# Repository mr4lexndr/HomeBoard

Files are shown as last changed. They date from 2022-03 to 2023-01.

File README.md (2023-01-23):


[][cc-by-nc-sa]

[][cc-by-nc-sa]

This work is licensed under a
[Creative Commons Attribution-NonCommercial-ShareAlike 4.0 International License][cc-by-nc-sa].

[cc-by-nc-sa]: http://creativecommons.org/licenses/by-nc-sa/4.0/
[cc-by-nc-sa-image]: https://licensebuttons.net/l/by-nc-sa/4.0/88x31.png
[cc-by-nc-sa-shield]: https://img.shields.io/badge/License-CC%20BY--NC--SA%204.0-lightgrey.svg

# HomeBoard
Simple ESP32 based 4 Channel LV board for controlling Home appliances with [HomeSpan](https://github.com/HomeSpan/HomeSpan).
HomeBoard was created to controll variety of LED strips, and other Low voltage appliances. 

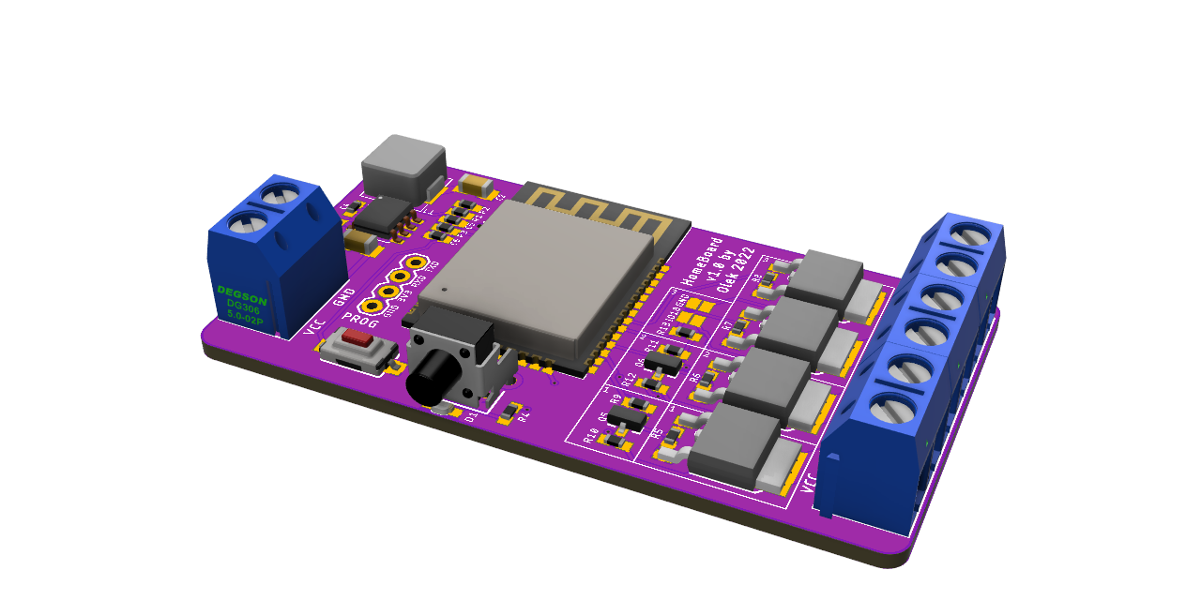
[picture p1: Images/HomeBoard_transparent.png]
HomeBoard


## Main Features
- Supply Voltage 3.5-30V
- Status LED and Control push button for easy configuration
- 4 PWM-eabled channels (0-Vin V, 25A)
- 2 channels can be configured with Logic Level Shifters to drive Neopixels etc.
- Switch or button option vailable.

## User Integration with HomeSpan
Status LED and Control Button are attached to deafault pins for most of the boards. S1 Button is also used as boot button during programming
- LED - GPIO2
- Button - GPIO0

## Variants
Four channels can be configured per requiremnts. Specific sections 1-3 has been marked on PCB. Only one group from each section should be soldered based on selected funtion. Available options:

| Channel | Main Function | Alternative |
| --- | --- | --- |
| 1 | Open Drain | Logic Level (0-Vin) |
| 2 | Open Drain | Logic Level (0-Vin) |
| 3 | Open Drain | Switch (GPIO18) |
| 4 | Open Drain | Switch (GND) |

## TO DO

- 3D printed case
- update power circuit with more common IC
- update programming connector and decrease the size of the board

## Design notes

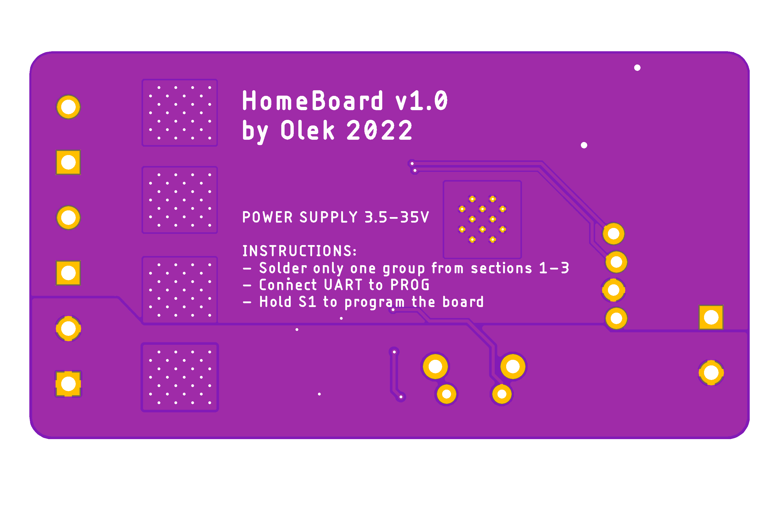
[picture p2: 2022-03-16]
Images/HomeBoard_Bottom.png

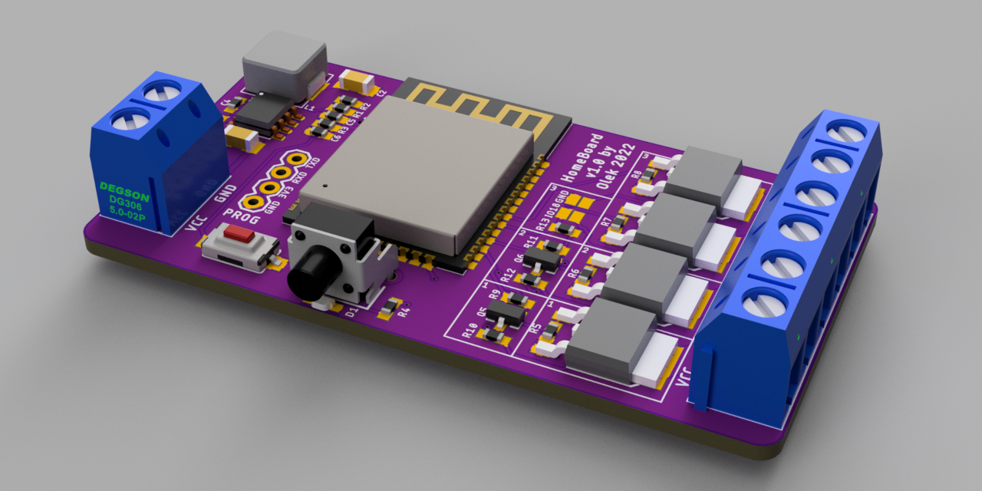
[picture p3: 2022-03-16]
Images/HomeBoard.png

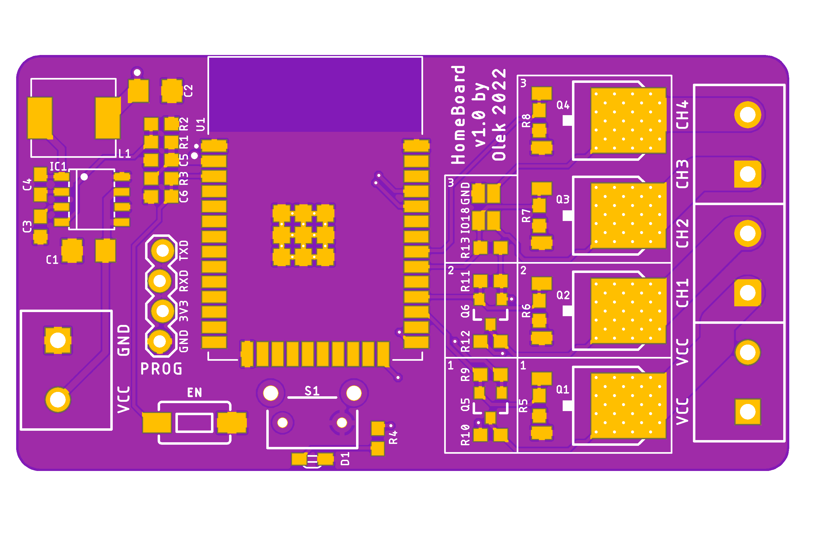
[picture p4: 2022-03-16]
Images/HomeBoard_Top.png

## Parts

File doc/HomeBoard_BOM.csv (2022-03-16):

Qty | Value | Device | Package | Parts | Description
4 |  | CONN_025MM | SCREWTERMINAL-5MM-2 | J1, J2, J3, J4 | Multi connection point. Often used as Generic Header-pin footprint for 0.1 inch spaced/style header connections
1 |  | CONN_04LOCK | 1X04_LOCK | PROG | Multi connection point. Often used as Generic Header-pin footprint for 0.1 inch spaced/style header connections
1 |  | INDUCTOR-7.3X6.6 | INDUCTOR-7.3X6.6 | L1 | Inductor
4 |  | MOSFET-N-DPAK | D-PAK_TO252AA | Q1, Q2, Q3, Q4 | N-Channel MOSFET in various packages
3 | 0.1uF | CAP-0603 | 0603 | C4, C5, C6
10 | 10k | RESISTOR0603 | 0603 | R3, R5, R6, R7, R8, R9, R10, R11, R12, R13 | Generic Resistor Package
1 | 10uF | CAP-1206 | 1206 | C1
1 | 140k | RESISTOR0603 | 0603 | R1 | Generic Resistor Package
1 | 1uF | CAP-0603 | 0603 | C3
1 | 22R | RESISTOR0603 | 0603 | R4 | Generic Resistor Package
1 | 22uF | CAP-1206 | 1206 | C2
1 | 47k | RESISTOR0603 | 0603 | R2 | Generic Resistor Package
2 | BSS138 | MOSFET-N-SOT23-3 | SOT23-3 | Q5, Q6 | N-Channel MOSFET in various packages
1 | ESP32-WROOM-32D | ESP32-WROOM-32D | MODULE_ESP32-WROOM-32D | U1 | Bluetooth, WiFi 802.11b/g/n, Bluetooth v4.2 + EDR, Class 1, 2 and 3 Transceiver Module 2.4GHz ~ 2.5GHz Integrated, Trace Surface Mount Check prices
1 | L6981 | L6981 | SO-8L | IC1 | L6981 38 V, 1.5 A synchronous step-down converter
1 | LTST-S220TBKT | LED-ANGLE-2MM | LED-ANGLE-2MM | D1 | LED (Generic)
1 | MOMENTARY-SWITCH-SPST-PTH-RIGHT-ANGLE-KIT | MOMENTARY-SWITCH-SPST-PTH-RIGHT-ANGLE-KIT | TACTILE_SWITCH_PTH_RIGHT_ANGLE_KIT | S1 | Momentary Switch (Pushbutton) - SPST
1 | MOMENTARY-SWITCH-SPST-SMD-6.0X3.5MM | MOMENTARY-SWITCH-SPST-SMD-6.0X3.5MM | TACTILE_SWITCH_SMD_6.0X3.5MM | EN | Momentary Switch (Pushbutton) - SPST

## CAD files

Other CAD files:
CAD/HomeBoard .f3d
CAD/HomeBoard.f3d

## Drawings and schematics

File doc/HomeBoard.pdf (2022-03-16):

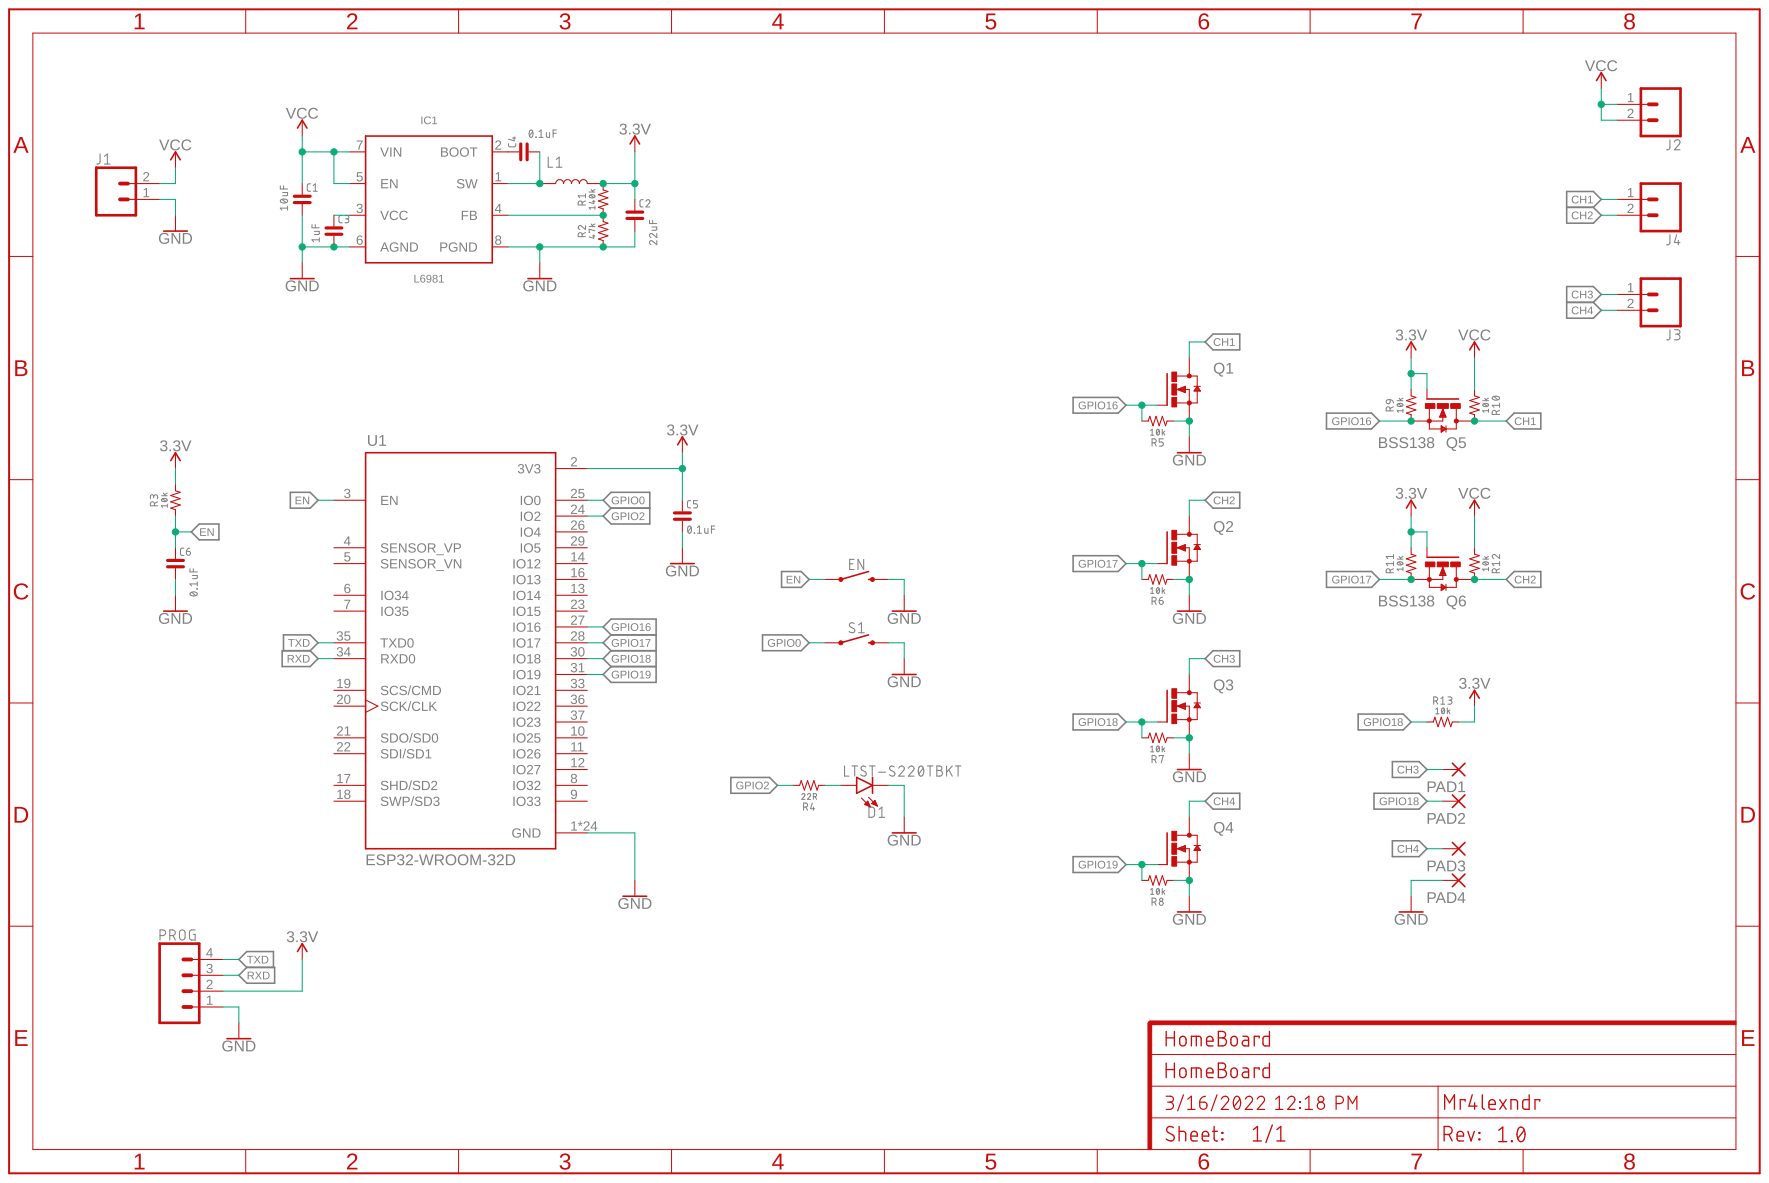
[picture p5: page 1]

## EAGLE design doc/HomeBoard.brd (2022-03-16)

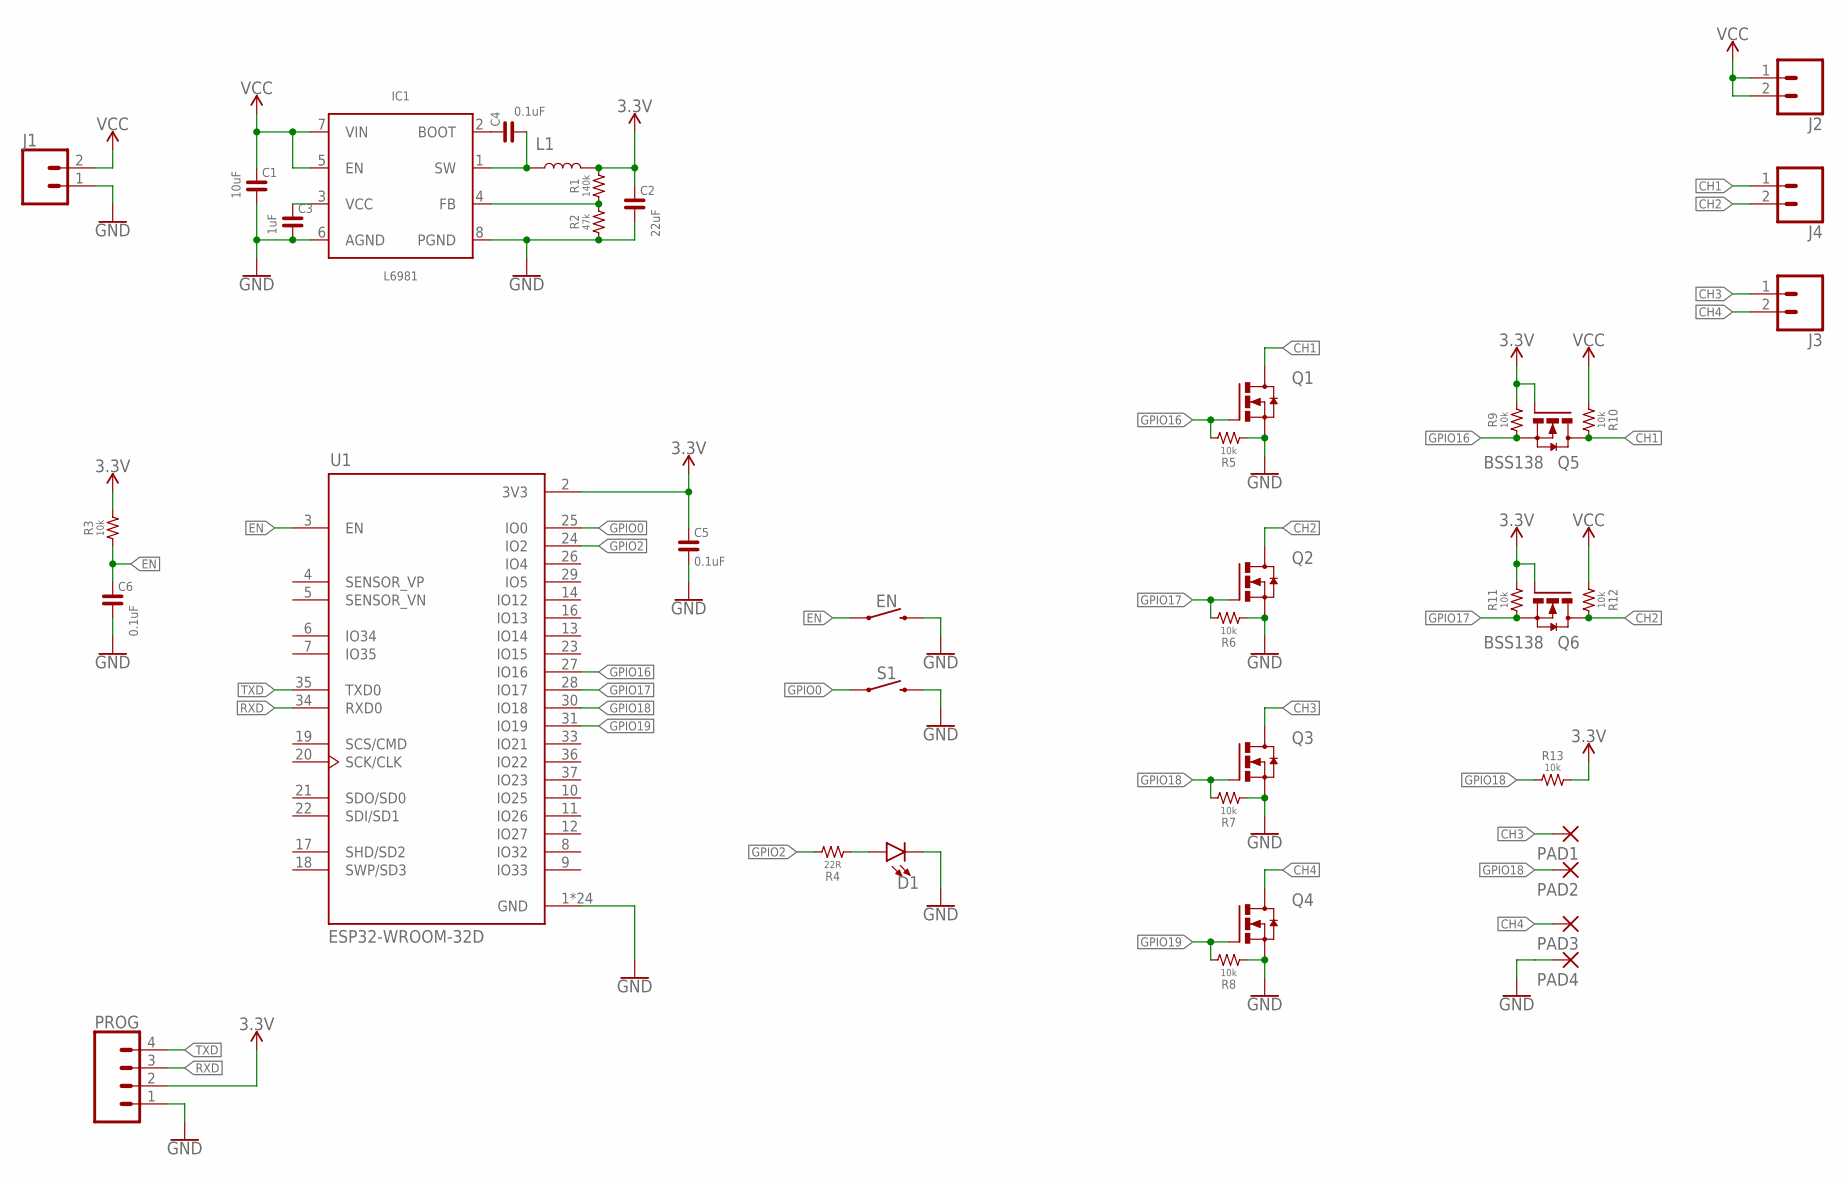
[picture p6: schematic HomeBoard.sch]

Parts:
C1: 10uF; 1206
C2: 22uF; 1206
C3: 1uF; 0603
C4, C5, C6: 0.1uF; 0603
D1: LED-ANGLE-2MM
EN: MOMENTARY-SWITCH-SPST-SMD-6.0X3.5MM; TACTILE_SWITCH_SMD_6.0X3.5MM
IC1: L6981; SO-8L
J1, J2, J3, J4: CONN_025MM; SCREWTERMINAL-5MM-2
L1: INDUCTOR-7.3X6.6
PAD1, PAD2, PAD3, PAD4: SMD_PADSMD-1X1.5MM; SMD1X1.5MM
PROG: CONN_04LOCK; 1X04_LOCK
Q1, Q2, Q3, Q4: MOSFET-N-DPAK; D-PAK_TO252AA
Q5, Q6: BSS138; SOT23-3
R1: 140k; 0603
R2: 47k; 0603
R3, R5, R6, R7, R8, R9, R10, R11, R12, R13: 10k; 0603
R4: 22R; 0603
S1: MOMENTARY-SWITCH-SPST-PTH-RIGHT-ANGLE-KIT; TACTILE_SWITCH_PTH_RIGHT_ANGLE_KIT
U1: ESP32-WROOM-32D; MODULE_ESP32-WROOM-32D

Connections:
3.3V: C2.2, C5.2, L1.P$2 (2), PROG.2, Q5.1 (G), Q6.1 (G), R1.2, R3.2, R9.2, R11.2, R13.2, U1.2 (3V3)
CH1: J4.1, Q1.4 (D), Q5.3 (D), R10.2
CH2: J4.2, Q2.4 (D), Q6.3 (D), R12.2
CH3: J3.1, PAD1.P$1, Q3.4 (D)
CH4: J3.2, PAD3.P$1, Q4.4 (D)
EN: C6.2, EN.1, R3.1, U1.3 (EN)
GND: C1.1, C2.1, C3.1, C5.1, C6.1, D1.C, EN.2, IC1.6 (AGND), IC1.8 (PGND), J1.1, PAD4.P$1, PROG.1, Q1.3 (S), Q2.3 (S), Q3.3 (S), Q4.3 (S), R2.1, R5.1, R6.1, R7.1, R8.1, S1.2, U1.1 (GND), U1.15 (GND), U1.38 (GND), U1.39_1 (GND), U1.39_2 (GND), U1.39_3 (GND), U1.39_4 (GND), U1.39_5 (GND), U1.39_6 (GND), U1.39_7 (GND), U1.39_8 (GND), U1.39_9 (GND), U1.39_10 (GND), U1.39_11 (GND), U1.39_12 (GND), U1.39_13 (GND), U1.39_14 (GND), U1.39_15 (GND), U1.39_16 (GND), U1.39_17 (GND), U1.39_18 (GND), U1.39_19 (GND), U1.39_20 (GND), U1.39_21 (GND)
GPIO0: S1.1, U1.25 (IO0)
GPIO2: R4.2, U1.24 (IO2)
GPIO16: Q1.1 (G), Q5.2 (S), R5.2, R9.1, U1.27 (IO16)
GPIO17: Q2.1 (G), Q6.2 (S), R6.2, R11.1, U1.28 (IO17)
GPIO18: PAD2.P$1, Q3.1 (G), R7.2, R13.1, U1.30 (IO18)
GPIO19: Q4.1 (G), R8.2, U1.31 (IO19)
unnamed: IC1.4 (FB), R1.1, R2.2
unnamed: C4.1, IC1.1 (SW), L1.P$1 (1)
unnamed: C4.2, IC1.2 (BOOT)
unnamed: D1.A, R4.1
unnamed: C3.2, IC1.3 (VCC)
RXD: PROG.3, U1.34 (RXD0)
TXD: PROG.4, U1.35 (TXD0)
VCC: C1.2, IC1.5 (EN), IC1.7 (VIN), J1.2, J2.1, J2.2, R10.1, R12.1

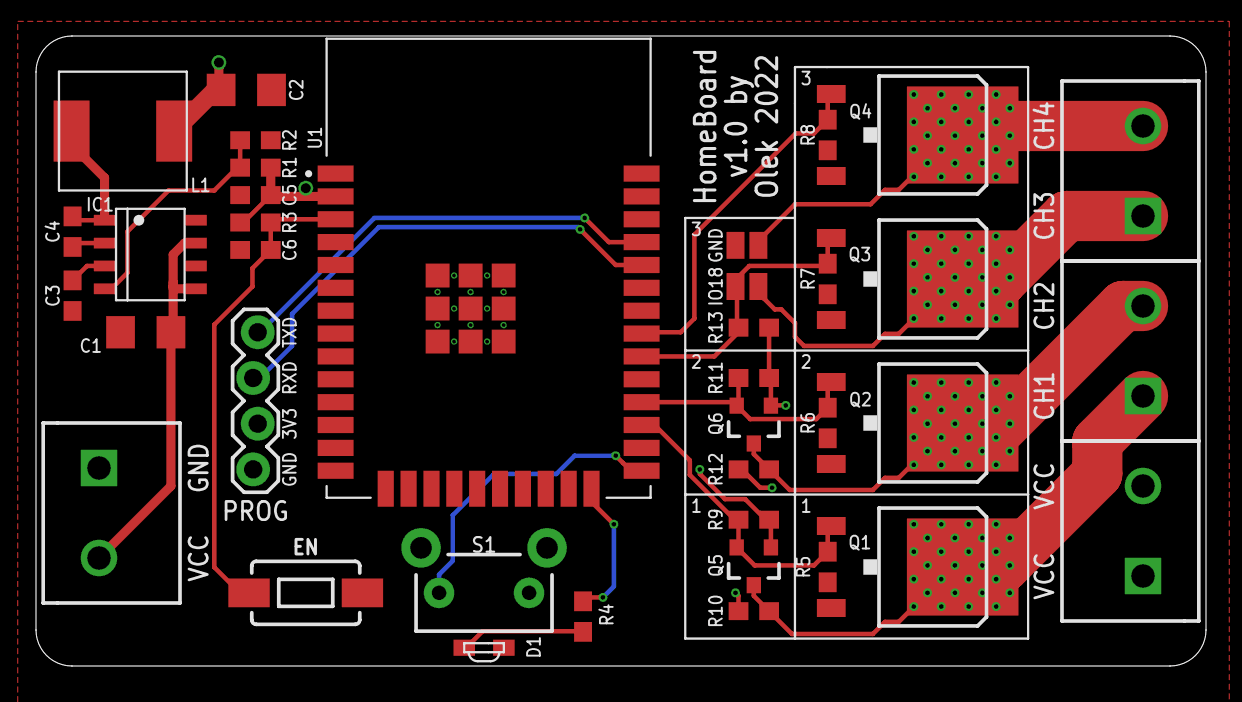
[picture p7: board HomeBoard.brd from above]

Board: 2 copper layers, 65.0 x 35.0 mm, 40 parts (0 on the bottom side), 21 nets.

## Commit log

2022-03-15 Eagle files
    [HomeBoard.brd, HomeBoard.sch]
2022-03-15 Fusion File
    [HomeBoard.f3d]
2022-03-16 Create HomeBoard .f3d
    [HomeBoard .f3d]

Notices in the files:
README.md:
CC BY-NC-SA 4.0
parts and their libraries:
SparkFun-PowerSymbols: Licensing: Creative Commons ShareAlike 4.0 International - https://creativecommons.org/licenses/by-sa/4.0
